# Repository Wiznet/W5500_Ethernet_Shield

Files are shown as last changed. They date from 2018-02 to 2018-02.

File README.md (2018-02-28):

# W5500 Ethernet Shield

## Overview

- Arduino Pin-compatible
- ARM mbed compatible operation
- Ethernet (W5500 Hardwired TCP/IP chip)

W5500 Ethernet shield is designed using the WIZnet W5500 chip. Please click the link for the further information about W5500. It supports both 3.3V & 5V. This Ethernet Shield is compatible with Arduino and ARM mbed Platform.

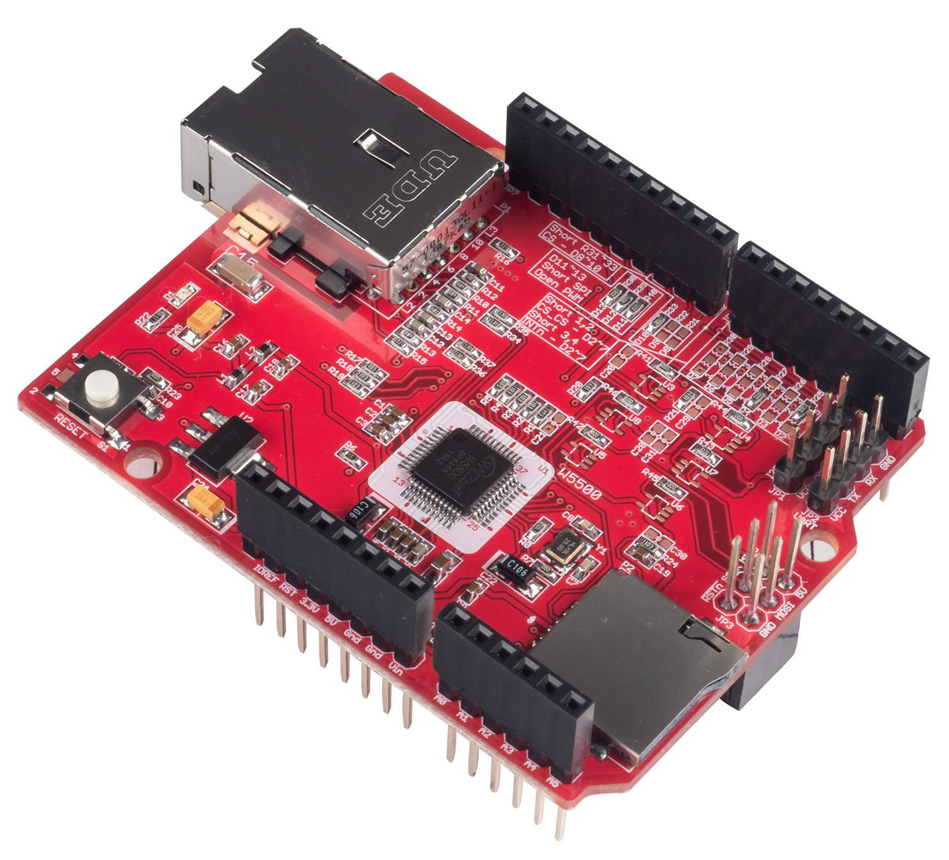
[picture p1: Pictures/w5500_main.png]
W5500 Ethernet Shield


### Available Board List

- ARM mbed Board
	- ARM mbed Platform : ARM mbed platform Site
	- FRDM-KL25Z : Freescale
	- NXP LPC800-MAX : NXP
- Arduino Board
	- Arduino board (e.g. the Uno, Mega, Due)
	- Arduino Leonardo
- Arduino-compatible Board
	- Seeeduino v3.0 : Based on Arduino Duemilanove

## Getting Started

- [Getting Started fot Arduino](https://wizwiki.net/wiki/doku.php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)
- [Ethernet/Ethernet2 library Reference](https://www.arduino.cc/en/Reference/Ethernet)

## Feature

- Ethernet controller W5500 of WIZnet
- SPI interface
- Internal 32Kbytes Tx/Rx buffer
- 10/100 Ethernet PHY embedded
- Hardwired TCP/IP Protocols : TCP, UDP, ICMP, IPv4, ARP, IGMP, PPPoE
- User Selectable GPIO pin
- Support SD-card slot for storage
- Support 3.3V and 5V

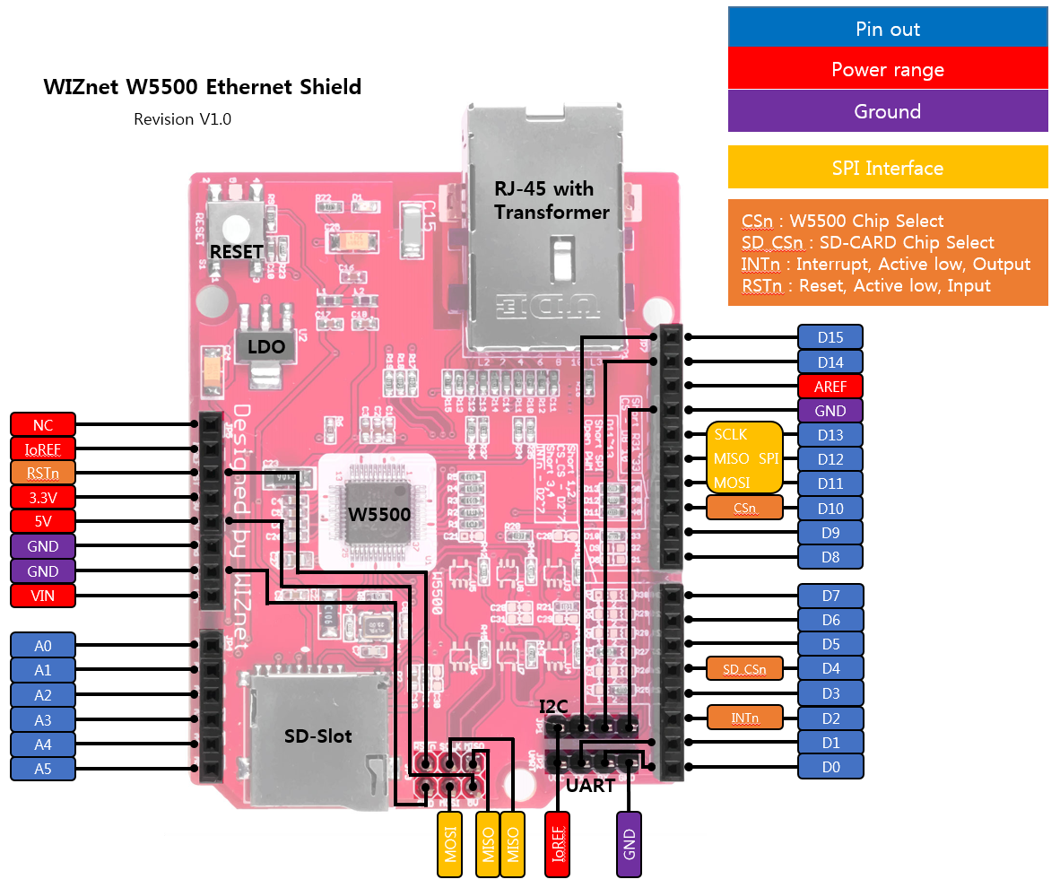
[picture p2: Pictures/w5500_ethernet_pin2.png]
W5500 Ethernet Shield Pin out


## Hardware Configuration
- RJ-45 with Transformer : Ethernet Port
- W5500 : a Hardwired TCP/IP Ethernet Controller
- RESET : Reset Ethernet shield and Arduino when pressed
- SD-Slot : support Micro SD card in FAT16 or FAT32 ; (Please read 'Caution' below)

## Pins usage on Arduino & ARM mbed

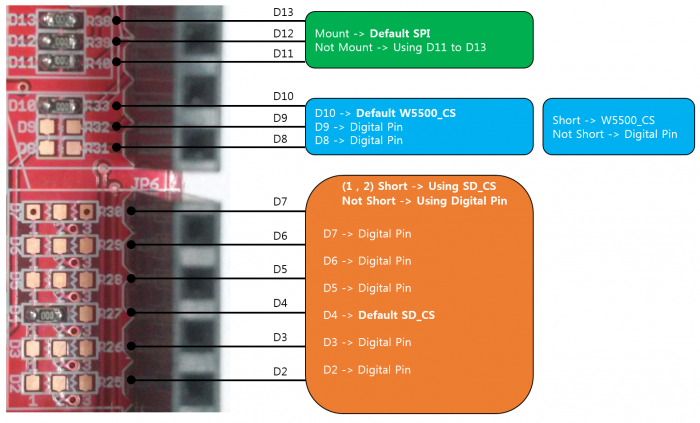
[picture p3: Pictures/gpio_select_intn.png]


W5500 Ethernet shield has several configurable GPIOs

- When you operate it with other modules, you may need to change 'Chip Select' pin to a different one.
- W5500 INTn pin is linked to D2 (2,3 Short). So, if you need INTn pin. You soldering to 0R Resistor to Dx pin

**Caution)** When the user uses 5V Platform, we cannot confirm a stable operation of SD-CARD. Therefore, though 5V Platform is safe to use after going through enough tests, it is highly recommended to mount buffer & 100nF Capacitor for a secure operation.

## SPI Operation & Timing Diagram

There is a W5500 inside W5500 Ethernet shield. Therefore SPI operation & Timing Diagram of Ethernet shield follows one of W5500. For more information about W5500 chip please also refer to the chip's datasheet:

- [W5500 Wiki](https://wizwiki.net/wiki/doku.php?id=products:w5500:start)

## Dimension

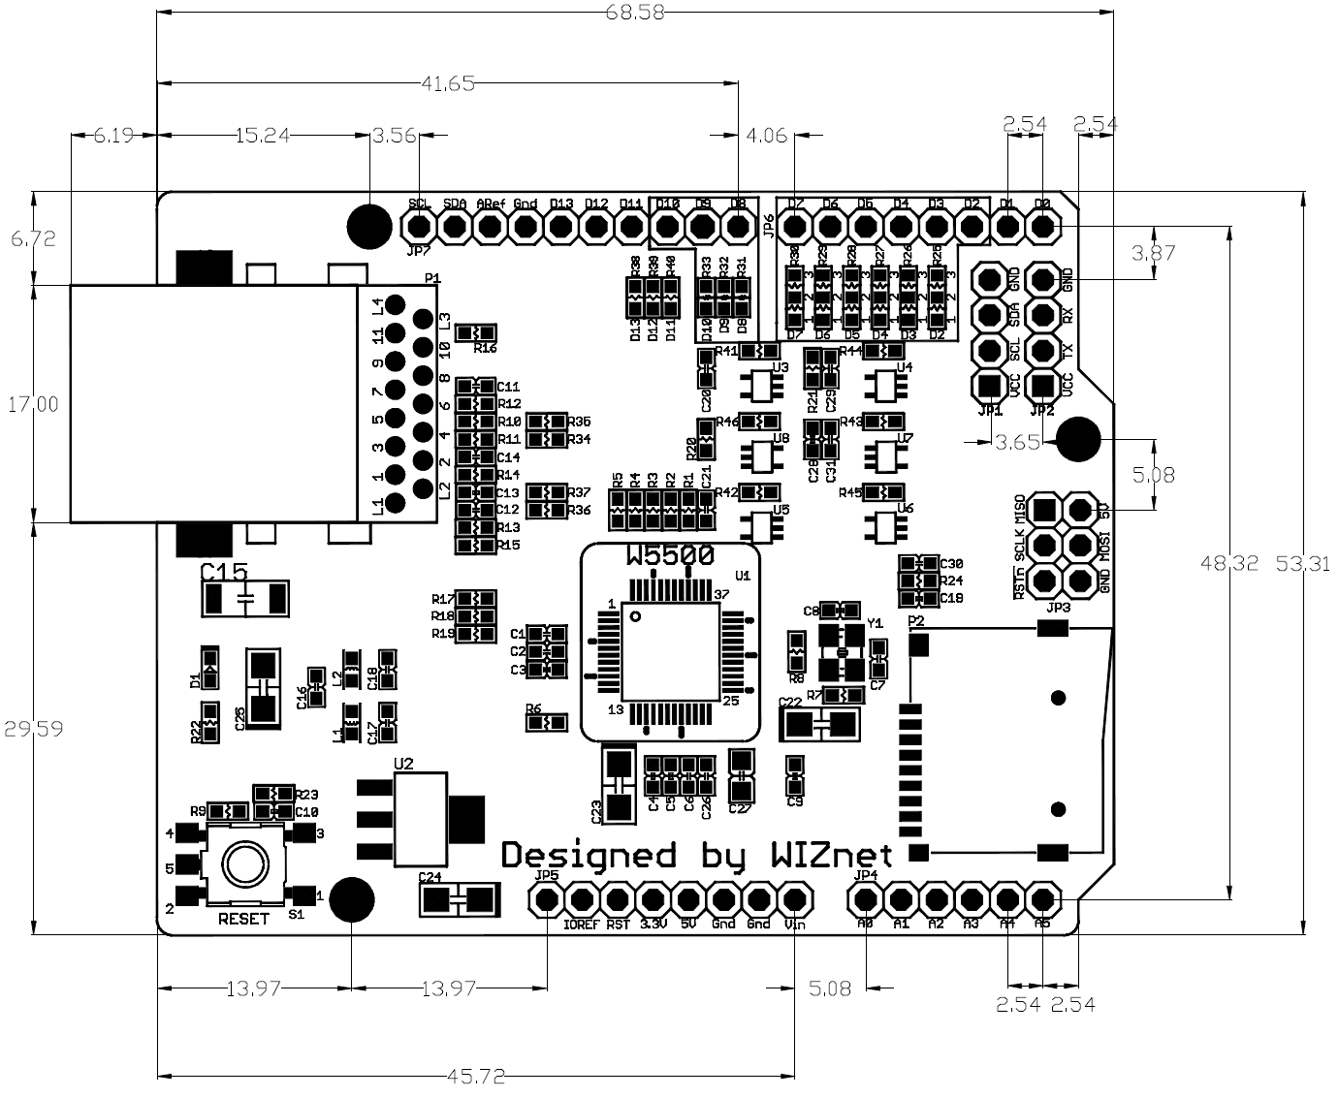
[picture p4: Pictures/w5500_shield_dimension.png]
W5500 Ethernet Shield Dimension


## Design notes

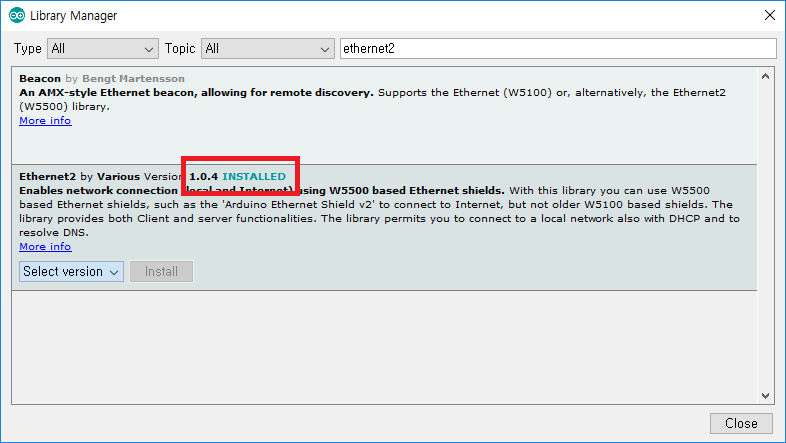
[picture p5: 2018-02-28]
Pictures/Add_Ethernet2_Library_4.png

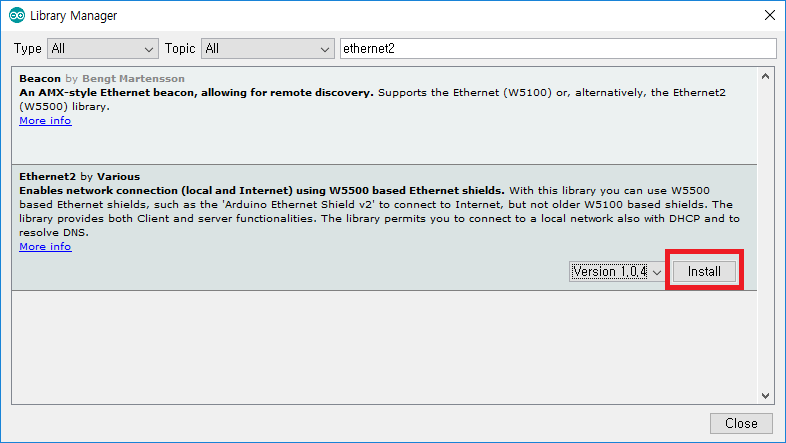
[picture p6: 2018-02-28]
Pictures/Add_Ethernet2_Library_3.png

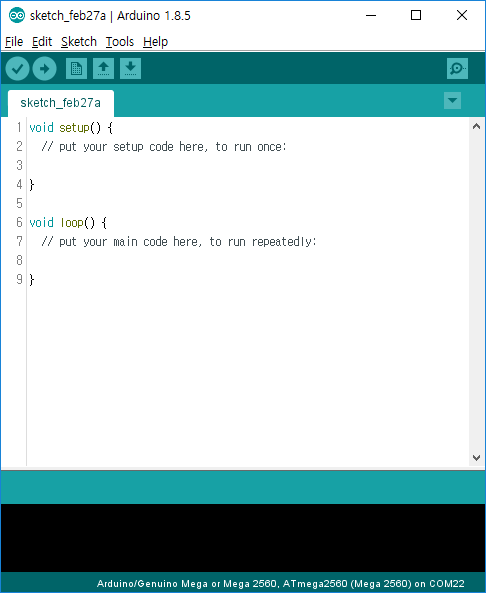
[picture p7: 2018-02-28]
Pictures/Add_Ethernet2_Library_0.png

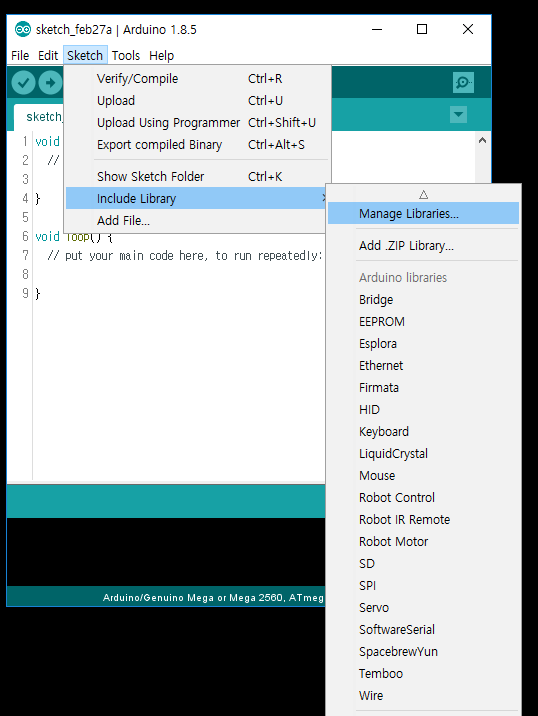
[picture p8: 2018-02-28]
Pictures/Add_Ethernet2_Library_1.png

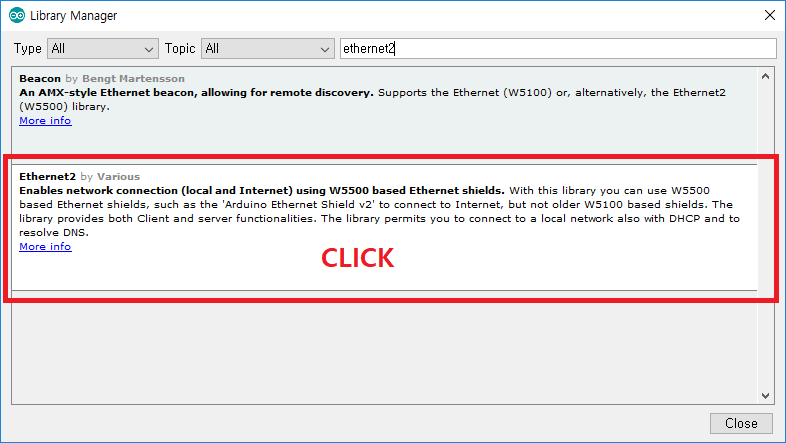
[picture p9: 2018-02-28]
Pictures/Add_Ethernet2_Library_2.png

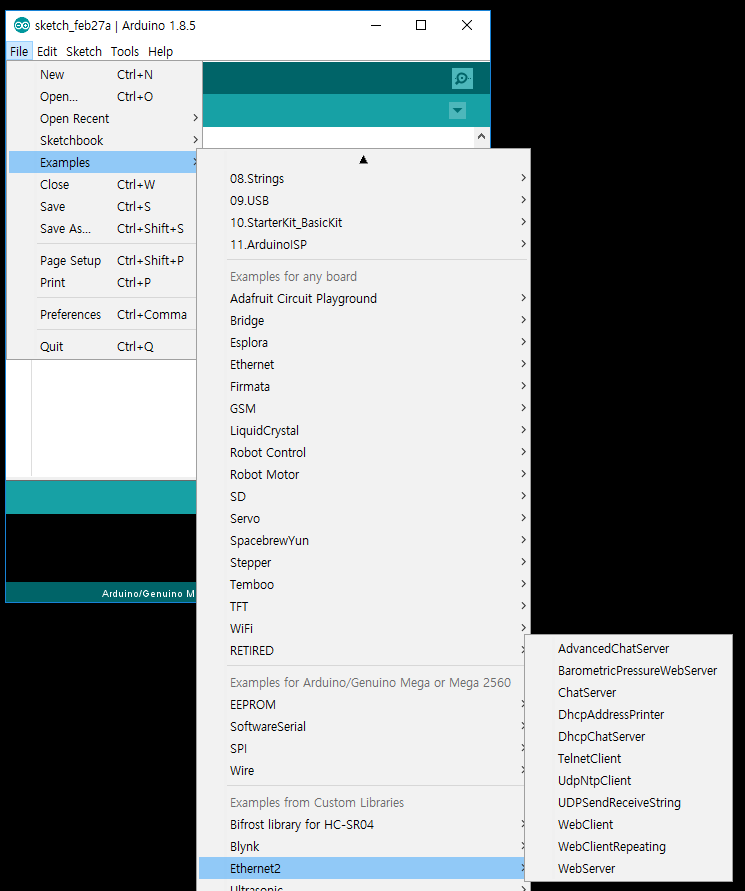
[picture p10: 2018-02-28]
Pictures/Add_Ethernet2_Library_5.png

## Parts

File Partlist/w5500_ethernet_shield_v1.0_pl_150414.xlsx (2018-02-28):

W5500 Ethernet shield Ver1.0 Partlist
Item | Q.ty | Reference | Part | Tech. Characteristics | Package | Description
1 | 2 | C14,C26 | 10nF | 25V-20% Ceramic | CASE 0603
2 | 12 | C1,C2,C3,C4,C5,C6,C9,C10,C16,C17,C18,C19 | 0.1uF | 50V-10% Ceramic | CASE 0603
3 | 6 | C20,C21,C28,C29,C30,C31 | 0.1uF | 50V-10% Ceramic | Not-Mount
4 | 1 | C15 | 1n/2KV | 1nF/2kV Ceramic | CASE 1808
5 | 2 | C22,C23 | 10uF/16V | Tantal CAP, 10uF/16V, +/-20% | Size A(3216)
6 | 1 | C24 | 1uF/16V | Tantal CAP, 1uF/16V, +/-20% | Size A(3216)
7 | 1 | C25 | 4.7uF/16V | Tantal CAP, 4.7uF/16V, +/-20% | Size A(3216)
8 | 1 | C11 | 22nF | 25V-20% Ceramic | CASE 0603
9 | 2 | C7,C8 | 18pF | 50V-5% Ceramic | CASE 0603
10 | 1 | C27 | 4.7uF | 25V-20% Ceramic | CASE 0805
11 | 2 | C12,C13 | 6.8nF | 50V-10% Ceramic | CASE 0603
12 | 6 | R26,R28,R29,R,30,R31,R32 | 0R | 1/10W-5% SMD | Not-Mount
13 | 12 | R1,R2,R3,R4,R5,R9,R17,R18,R19,R20,R21,R24 | 10k | 1/10W-5% SMD | CASE 0603
14 | 1 | R6 | 12.4K (1%) | 1/10W-1% SMD | CASE 0603
15 | 1 | R12 | 10R (1%) | 1/10W-1% SMD | CASE 0603
16 | 1 | R8 | 1M | 1/10W-5% SMD | CASE 0603
17 | 3 | R15,R16,R22 | 330R | 1/10W-5% SMD | CASE 0603
18 | 4 | R10,R11,R13,R14 | 49R9 (1%) | 1/10W-1% SMD | CASE 0603
19 | 4 | R34,R35,R36,R37 | 33R | 1/10W-5% SMD | CASE 0603
20 | 2 | R25, R27 | 0R (JUMPER) | 1/10W-5% SMD | CASE 0603 | R25은 2 , 3 번 0R 연결 R27은 1 , 2 번 0R 연결
21 | 12 | R7,R23,R33,R38,R39,R40,R41,R42,R43,R44,R45,R46 | 0R | 1/10W-5% SMD | CASE 0603
22 | 1 | D1 | Red LED SMD 1608 | CHIP-LED, RED | CASE 0603
23 | 2 | L1,L2 | HH-1M1608-121JT | Bead for Power Line, 120[ohm] | CASE 0603
24 | 2 | JP1,JP2 | 2.54mm Pin-Header 1x4 | 2.54mm Pin Header 1x4, Male | DIP
25 | 1 | JP3 | 9299-11-2x3 F | 2.54mm Pin Header Socket 2x3, Female | DIP, Black
26 | 1 | JP4 | 9299-11-1x6 F | 2.54mm Pin Header Socket 1x6, Female | DIP, Black
27 | 2 | JP5,JP6 | 9299-11-1x8 F | 2.54mm Pin Header Socket 1x8, Female | DIP, Black
28 | 1 | JP7 | 9299-11-1x10 F | 2.54mm Pin Header Socket 1x10, Female | DIP, Black
29 | 1 | S1 | SKHMPSE010 | 6.2 X 6.5mm TACT Switch | SMD
30 | 1 | U1 | W5500 | TCP/IP | 48LQFP
31 | 6 | U3,U4,U5,U6,U7,U8 | 74LVC1G125DCK | Single 3-State Buffer(SC-70(DCK)) | Not-Mount
32 | 1 | U2 | AME8815BEGT330Z | 3.3V 1A LDO | SOT-223
33 | 1 | P1 | 57-00013QL11-1 | RJ45 Tab UP, Slim type, With Transformer | DIP
34 | 1 | P2 | 7MSDP-B0-1012 | Micro SD Card Socket (PUSH-PUSH Type) | 7MSDP-B0-1012
35 | 1 | Y1 | 82J0626-25Mhz | X-tal 25MHz, 3.2x2.5 SMD ,CL=18pF, I30 | SMD3225, 4- PAD
36 | 1 | W5500_Ethernet_shield | PCB | 2-Layer, 68.58mm x 53.31mm, PCB - 빨간색, Silk - 흰색

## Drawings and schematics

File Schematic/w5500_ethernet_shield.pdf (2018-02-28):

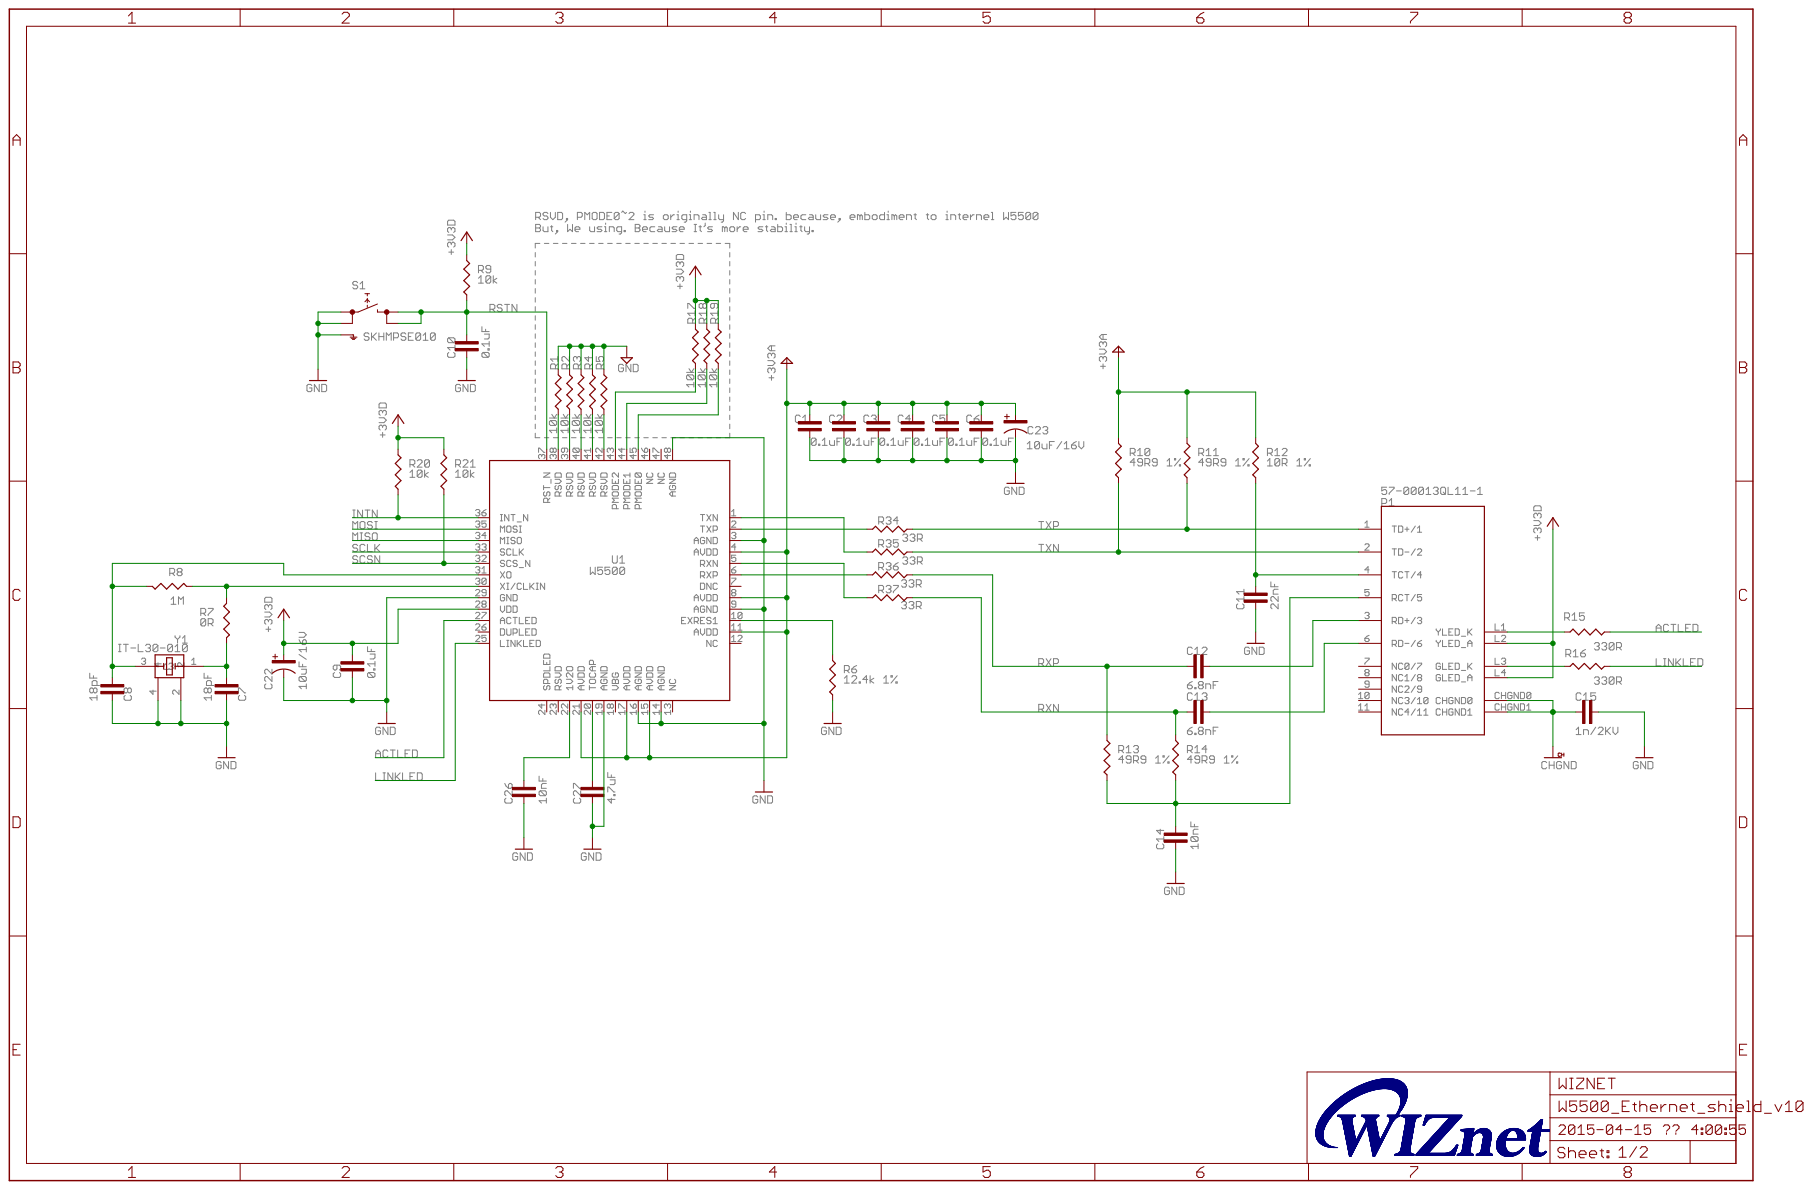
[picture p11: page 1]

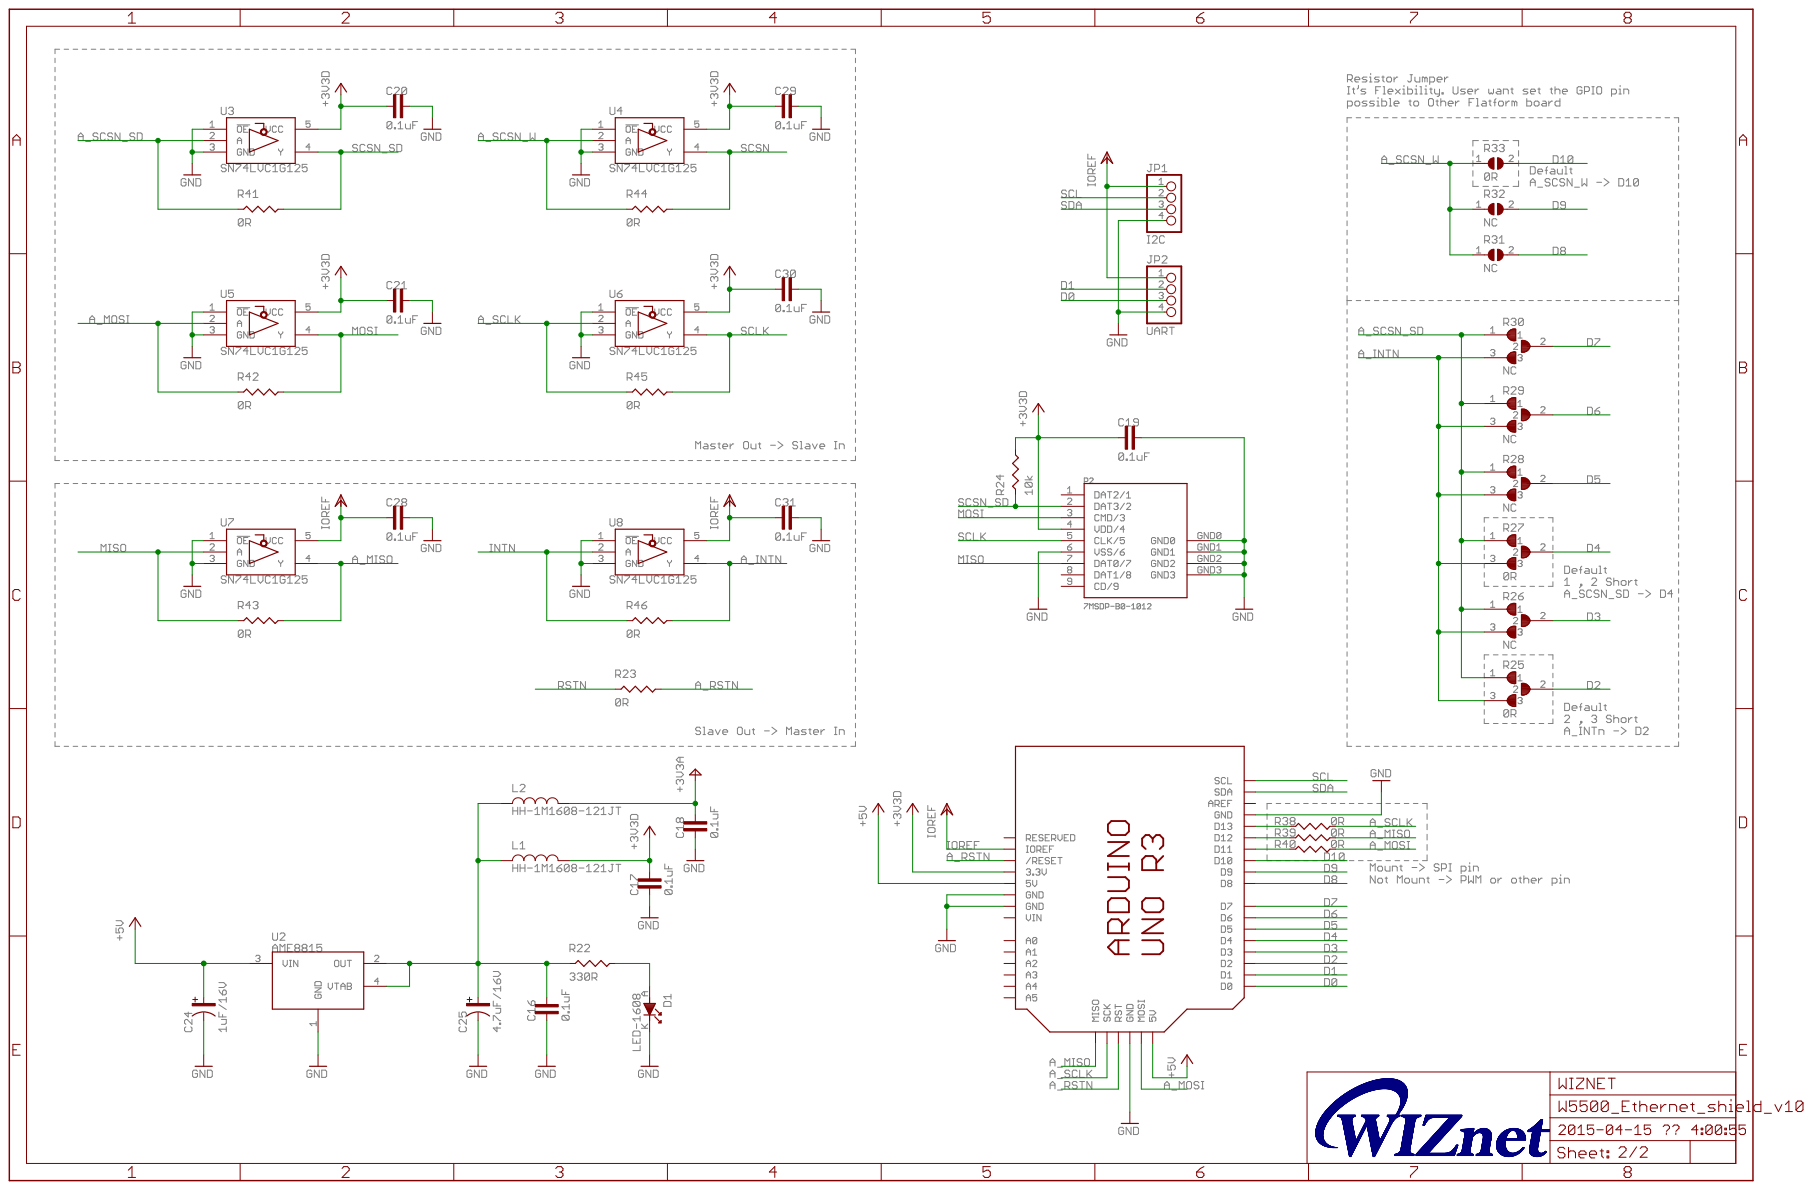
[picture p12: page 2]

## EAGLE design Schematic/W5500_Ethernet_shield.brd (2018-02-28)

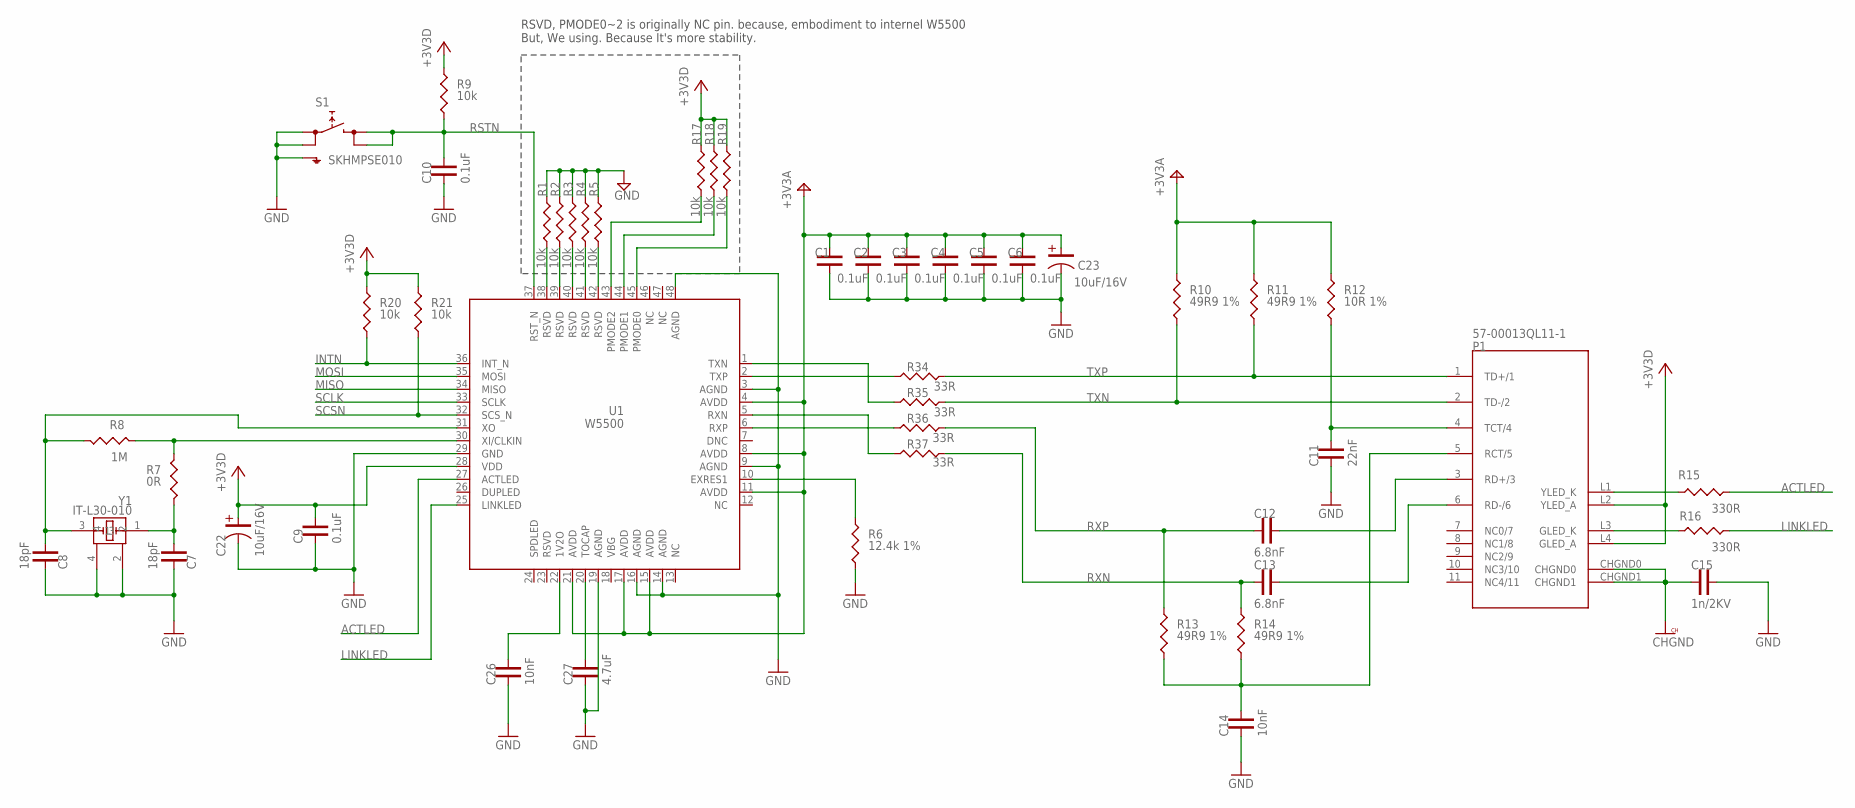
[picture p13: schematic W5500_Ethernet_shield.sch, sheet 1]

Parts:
C1, C2, C3, C4, C5, C6, C9, C10: 0.1uF; C-1608
C7, C8: 18pF; C-1608
C11: 22nF; C-1608
C12, C13: 6.8nF; C-1608
C14, C26: 10nF; C-1608
C15: 1n/2KV; C-1808
C22, C23: 10uF/16V; C-3216(TANTAL)
C27: 4.7uF; C-2012
P1: 57-00013QL11-1
R1, R2, R3, R4, R5, R9, R17, R18, R19, R20, R21: 10k; R-1608
R6: 12.4k 1%; R-1608
R7: 0R; R-1608
R8: 1M; R-1608
R10, R11, R13, R14: 49R9 1%; R-1608
R12: 10R 1%; R-1608
R15, R16: 330R; R-1608
R34, R35, R36, R37: 33R; R-1608
S1: SKHMPSE010; SKHMPXE010
U1: W5500
Y1: IT-L30-010

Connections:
+3V3: C9.2, C22.1, P1.L2 (YLED_A), P1.L4 (GLED_A), R9.2, R17.2, R18.2, R19.2, R20.2, R21.2, U1.28 (VDD); also elsewhere on the board
+3V3A: C1.2, C2.2, C3.2, C4.2, C5.2, C6.2, C23.1, R10.2, R11.2, R12.2, U1.4 (AVDD), U1.8 (AVDD), U1.11 (AVDD), U1.15 (AVDD), U1.17 (AVDD), U1.21 (AVDD); also elsewhere on the board
ACTLED: R15.1, U1.27 (ACTLED)
CHGND: C15.P$1, P1.CHGND0, P1.CHGND1
GND: C1.1, C2.1, C3.1, C4.1, C5.1, C6.1, C7.1, C8.1, C9.1, C10.1, C11.1, C14.1, C15.P$2, C22.2, C23.2, C26.1, C27.P$1, R1.2, R2.2, R3.2, R4.2, R5.2, R6.1, S1.1 (1.1), S1.2 (1.2), S1.5 (SH), U1.3 (AGND), U1.9 (AGND), U1.14 (AGND), U1.16 (AGND), U1.19 (AGND), U1.29 (GND), U1.48 (AGND), Y1.2, Y1.4; also elsewhere on the board
INTN: R20.1, U1.36 (INT_N); also elsewhere on the board
LINKLED: R16.1, U1.25 (LINKLED)
MISO: U1.34 (MISO); also elsewhere on the board
MOSI: U1.35 (MOSI); also elsewhere on the board
unnamed: R17.1, U1.43 (PMODE2)
unnamed: R18.1, U1.44 (PMODE1)
unnamed: R19.1, U1.45 (PMODE0)
unnamed: R1.1, U1.38 (RSVD)
unnamed: R2.1, U1.39 (RSVD)
unnamed: R3.1, U1.40 (RSVD)
unnamed: R4.1, U1.41 (RSVD)
unnamed: R5.1, U1.42 (RSVD)
unnamed: R7.2, R8.2, U1.30 (XI/CLKIN)
unnamed: C27.P$2, U1.20 (TOCAP)
unnamed: C26.2, U1.22 (1V2O)
unnamed: C12.2, P1.3 (RD+/3)
unnamed: R6.2, U1.10 (EXRES1)
unnamed: C13.2, P1.6 (RD-/6)
unnamed: C14.2, P1.5 (RCT/5), R13.1, R14.1
unnamed: R36.2, U1.6 (RXP)
unnamed: C11.2, P1.4 (TCT/4), R12.1
unnamed: C8.2, R8.1, U1.31 (XO), Y1.3
unnamed: P1.L3 (GLED_K), R16.2
unnamed: P1.L1 (YLED_K), R15.2
unnamed: R37.2, U1.5 (RXN)
unnamed: R34.2, U1.2 (TXP)
unnamed: R35.2, U1.1 (TXN)
unnamed: C7.2, R7.1, Y1.1
RSTN: C10.2, R9.1, S1.3 (2.1), S1.4 (2.2), U1.37 (RST_N); also elsewhere on the board
RXN: C13.1, R14.2, R37.1
RXP: C12.1, R13.2, R36.1
SCLK: U1.33 (SCLK); also elsewhere on the board
SCSN: R21.1, U1.32 (SCS_N); also elsewhere on the board
TXN: P1.2 (TD-/2), R10.1, R35.1
TXP: P1.1 (TD+/1), R11.1, R34.1

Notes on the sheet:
RSVD, PMODE0~2 is originally NC pin. because, embodiment to internel W5500 But, We using. Because It's more stability.

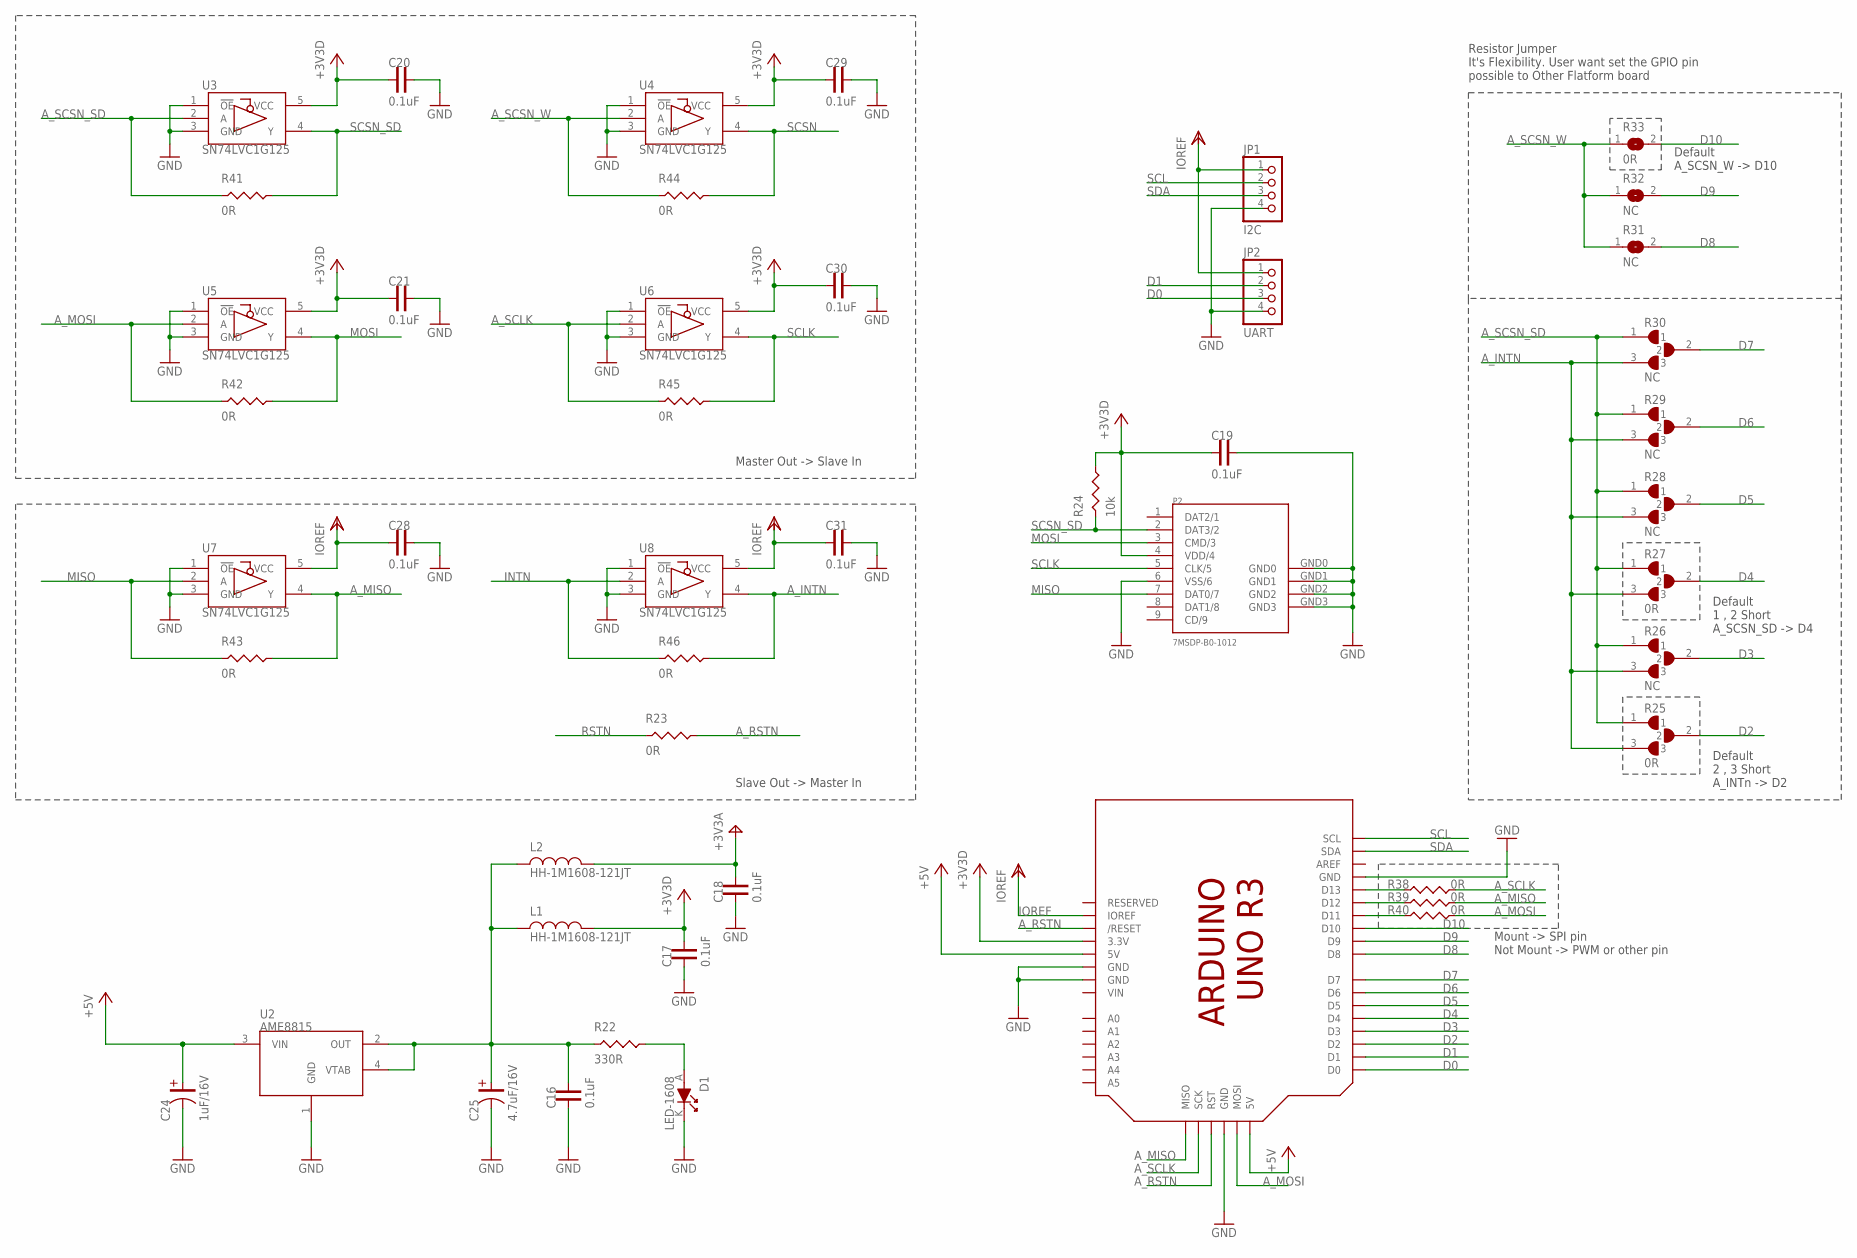
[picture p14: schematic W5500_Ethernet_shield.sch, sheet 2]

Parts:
C16, C17, C18, C19, C20, C21, C28, C29, C30, C31: 0.1uF; C-1608
C24: 1uF/16V; C-3216(TANTAL)
C25: 4.7uF/16V; C-3216(TANTAL)
D1: LED-1608
JP1: I2C; 1X04
JP2: UART; 1X04
L1, L2: HH-1M1608-121JT; L-1608
P2: 7MSDP-B0-1012
R22: 330R; R-1608
R23, R38, R39, R40, R41, R42, R43, R44, R45, R46: 0R; R-1608
R24: 10k; R-1608
R25, R27: 0R; RESISTOR_JUMPER_3
R26, R28, R29, R30: NC; RESISTOR_JUMPER_3
R31, R32: NC; SJW
R33: 0R; SJW
U2: AME8815
U3, U4, U5, U6, U7, U8: SN74LVC1G125
U$1: ARDUINO_R3_ICSP; ARDUINOR3_ICSP

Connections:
+3V3: C17.2, C19.1, C20.1, C21.1, C29.1, C30.1, L1.P$2 (2), P2.4 (VDD/4), R24.2, U3.5 (VCC), U4.5 (VCC), U5.5 (VCC), U6.5 (VCC), U$1.3V (3.3V); also elsewhere on the board
+3V3A: C18.2, L2.P$2 (2); also elsewhere on the board
+5V: C24.1, U2.3 (VIN), U$1.5V, U$1.5V_ICSP (5V)
A_INTN: R25.3, R26.3, R27.3, R28.3, R29.3, R30.3, R46.2, U8.4 (Y)
A_MISO: R39.2, R43.2, U7.4 (Y), U$1.MISO
A_MOSI: R40.2, R42.1, U5.2 (A), U$1.MOSI
A_RSTN: R23.2, U$1.RESET (/RESET), U$1.RESET_ICSP (RST)
A_SCLK: R38.2, R45.1, U6.2 (A), U$1.SCK
A_SCSN_SD: R25.1, R26.1, R27.1, R28.1, R29.1, R30.1, R41.1, U3.2 (A)
A_SCSN_W: R31.1, R32.1, R33.1, R44.1, U4.2 (A)
D0: JP2.3, U$1.D0
D1: JP2.2, U$1.D1
D2: R25.2, U$1.D2
D3: R26.2, U$1.D3
D4: R27.2, U$1.D4
D5: R28.2, U$1.D5
D6: R29.2, U$1.D6
D7: R30.2, U$1.D7
D8: R31.2, U$1.D8
D9: R32.2, U$1.D9
D10: R33.2, U$1.D10
GND: C16.1, C17.1, C18.1, C19.2, C20.2, C21.2, C24.2, C25.2, C28.2, C29.2, C30.2, C31.2, D1.K, JP1.4, JP2.4, P2.6 (VSS/6), P2.GND0, P2.GND1, P2.GND2, P2.GND3, U2.1 (GND), U3.1 (!OE), U3.3 (GND), U4.1 (!OE), U4.3 (GND), U5.1 (!OE), U5.3 (GND), U6.1 (!OE), U6.3 (GND), U7.1 (!OE), U7.3 (GND), U8.1 (!OE), U8.3 (GND), U$1.GND, U$1.GND@1 (GND), U$1.GND@2 (GND), U$1.GND@3 (GND); also elsewhere on the board
INTN: R46.1, U8.2 (A); also elsewhere on the board
IOREF: C28.1, C31.1, JP1.1, JP2.1, U7.5 (VCC), U8.5 (VCC), U$1.IOREF
MISO: P2.7 (DAT0/7), R43.1, U7.2 (A); also elsewhere on the board
MOSI: P2.3 (CMD/3), R42.2, U5.4 (Y); also elsewhere on the board
unnamed: D1.A, R22.2
unnamed: R38.1, U$1.D13
unnamed: C16.2, C25.1, L1.1, L2.1, R22.1, U2.2 (OUT), U2.4 (VTAB)
unnamed: R39.1, U$1.D12
unnamed: R40.1, U$1.D11
RSTN: R23.1; also elsewhere on the board
SCL: JP1.2, U$1.SCL
SCLK: P2.5 (CLK/5), R45.2, U6.4 (Y); also elsewhere on the board
SCSN: R44.2, U4.4 (Y); also elsewhere on the board
SCSN_SD: P2.2 (DAT3/2), R24.1, R41.2, U3.4 (Y)
SDA: JP1.3, U$1.SDA

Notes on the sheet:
Master Out -> Slave In
Slave Out -> Master In
Resistor Jumper It's Flexibility. User want set the GPIO pin possible to Other Flatform board
Default 2 , 3 Short A_INTn -> D2
Default 1 , 2 Short A_SCSN_SD -> D4
Default A_SCSN_W -> D10
Mount -> SPI pin Not Mount -> PWM or other pin

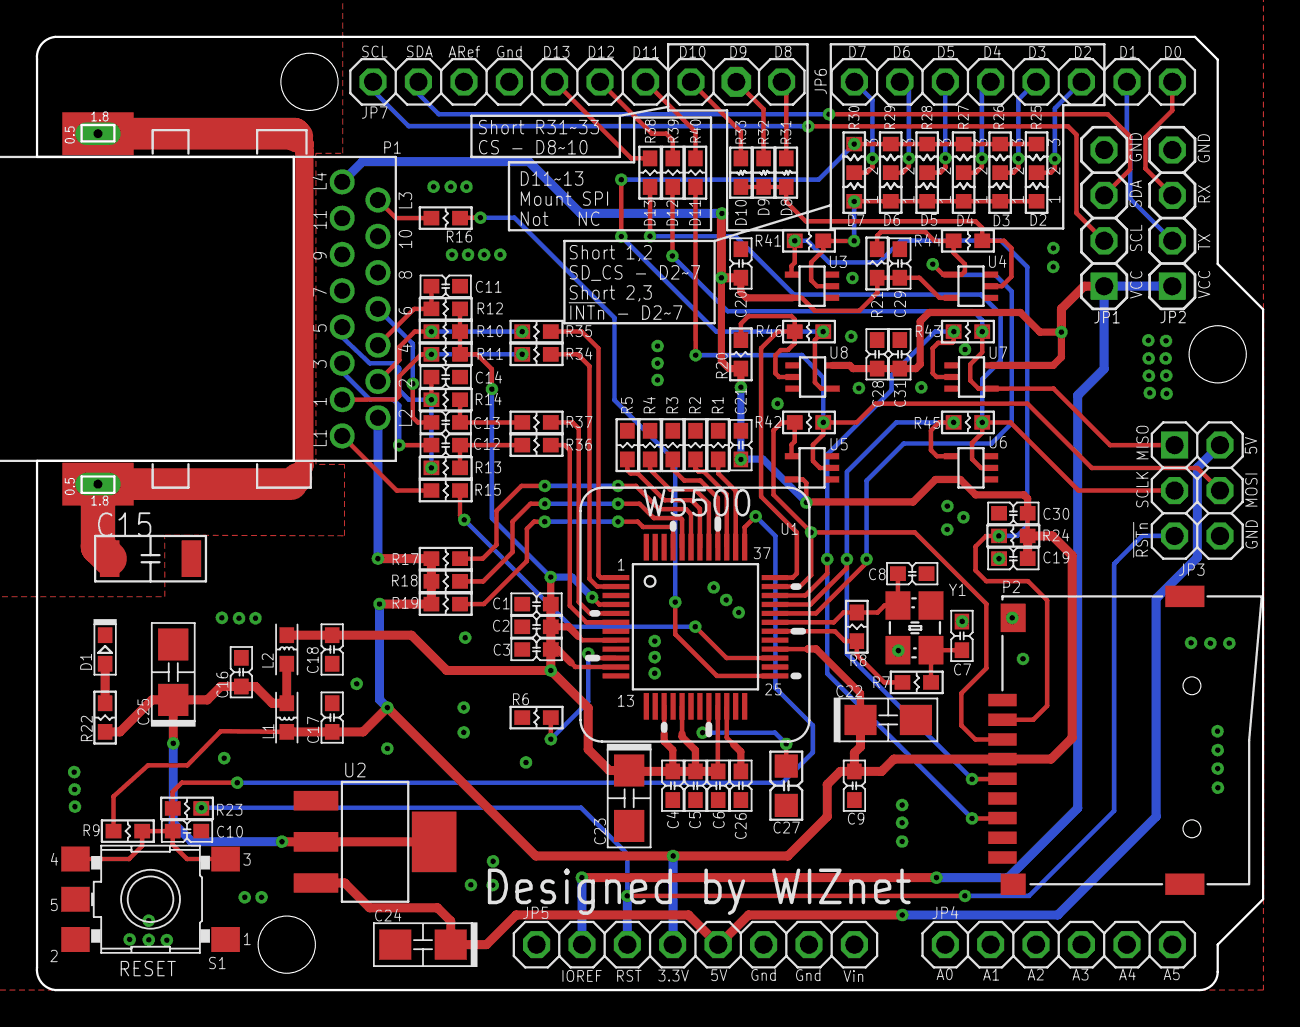
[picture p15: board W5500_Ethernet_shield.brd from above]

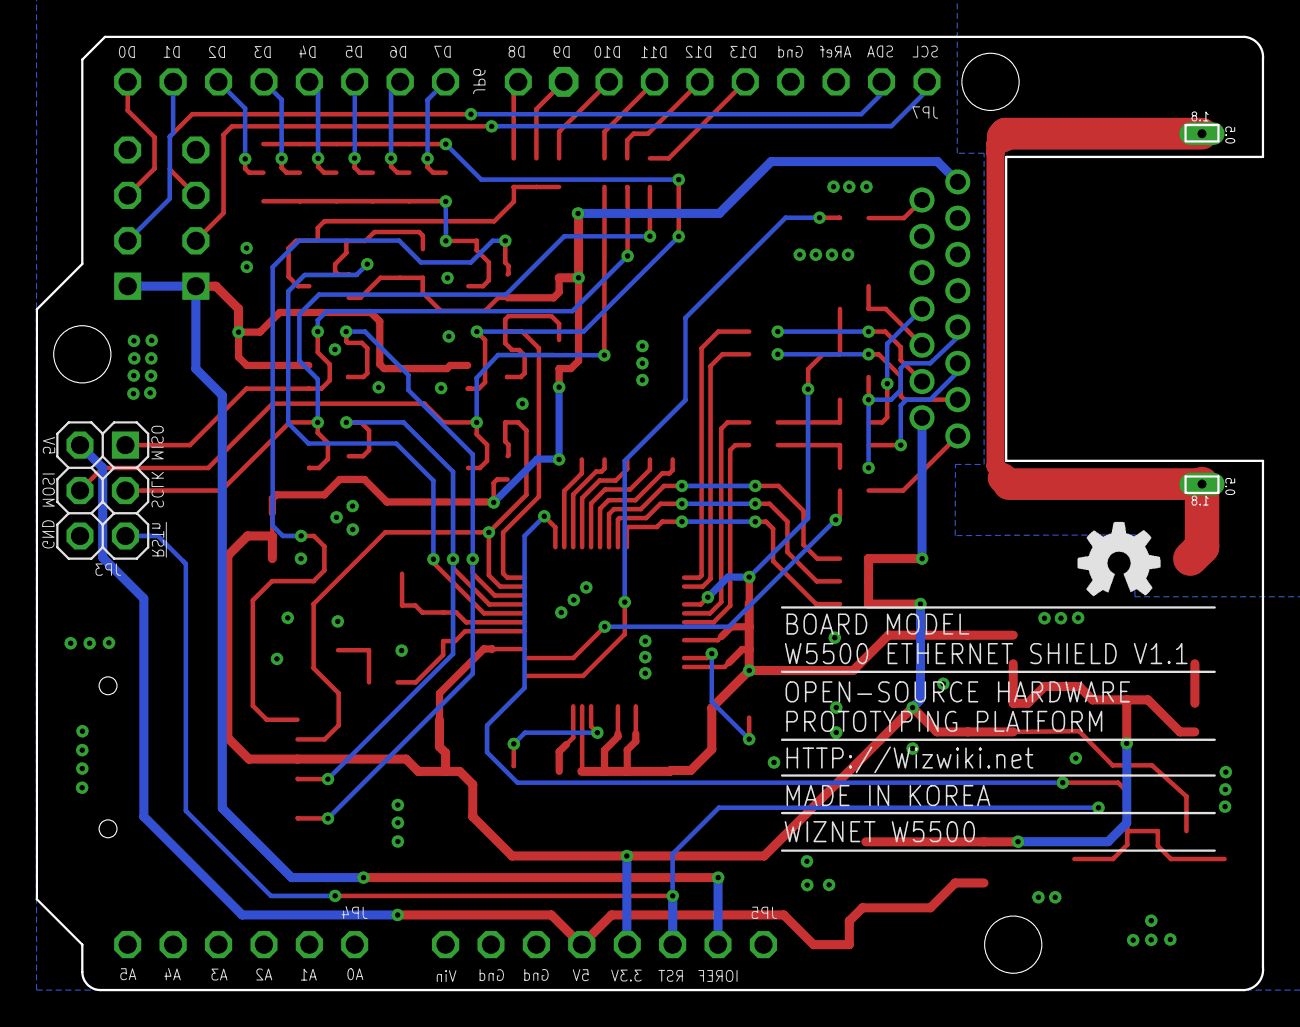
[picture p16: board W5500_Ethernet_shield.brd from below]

Board: 2 copper layers, 68.6 x 53.3 mm, 97 parts (2 on the bottom side), 68 nets.

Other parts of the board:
U$4: OSHP-LOGO
U$7: IOPIOT_LOGO_3

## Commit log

2018-02-28 Initial Release
    [W5500_Ethernet_shield.brd, W5500_Ethernet_shield.sch, w5500_ethernet_shield_v1.0_pl_150414.xlsx]
2018-02-28 added gerber files
    Added W5500 Ethernet shield V1.0 gerber file
2018-02-28 Update to Rev1.1 files
    In Rev 1.0, GND pin of “RESET” button(S1) was floating.
    This change in Rev1.1 will solve the floating problem. (Connect to GND
    with adding VIA.)
    Refer to below picture.
    GND is reinforced by adding via hole to whole board
    Via located was close to D11 pattern(R20). so that via is separated.
    [W5500_Ethernet_shield.brd]
